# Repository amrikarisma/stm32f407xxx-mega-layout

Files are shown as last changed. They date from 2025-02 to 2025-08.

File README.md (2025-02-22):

# stm32f407xxx-mega-layout

## Made For Speeduino and RusEFI Firmware
This board is inspired by Pazi88 and Mega100 boards. Thank you very much to those who created the board first.

### Front
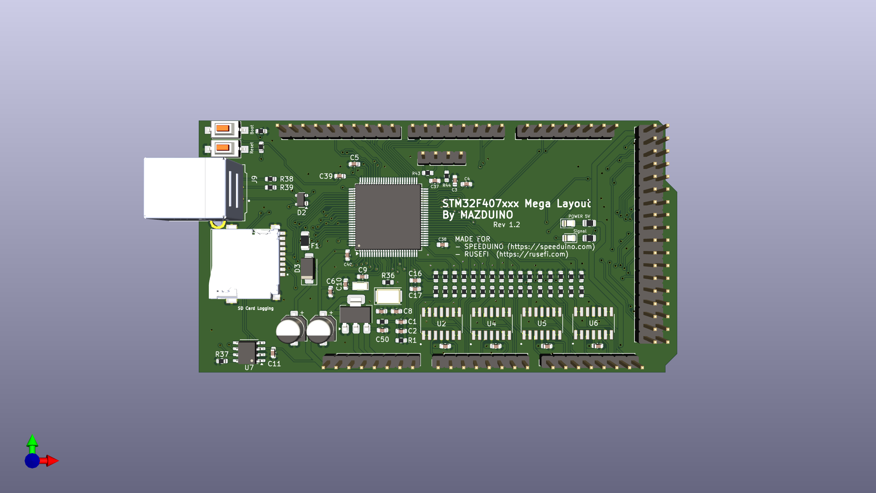
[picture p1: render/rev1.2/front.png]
front


### Back
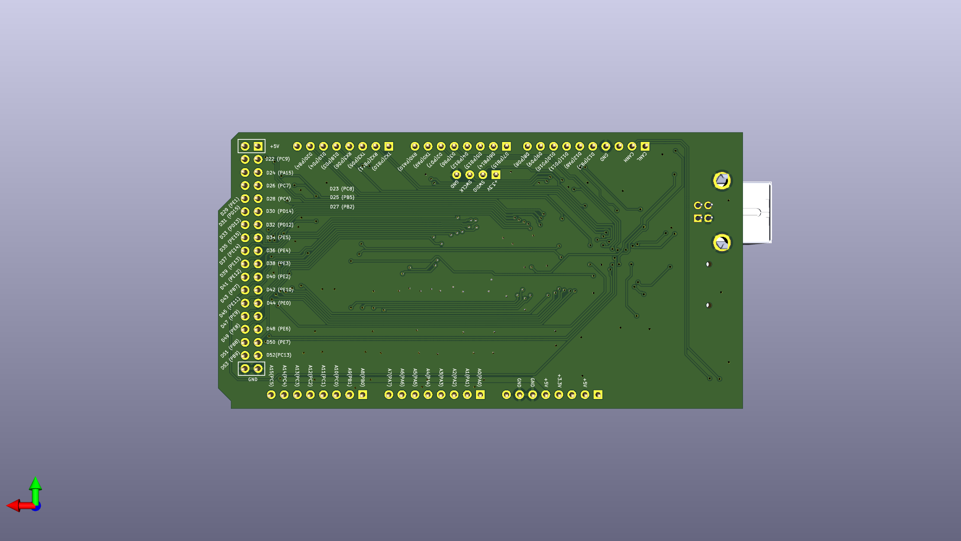
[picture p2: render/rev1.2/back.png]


### Schematic 
[schematic-stm32f407xxx-mega-layout.pdf](schematic-stm32f407xxx-mega-layout.pdf)

### Thanks to
- https://github.com/pazi88/STM32_mega
- https://github.com/rusefi/fw-custom-mega100/

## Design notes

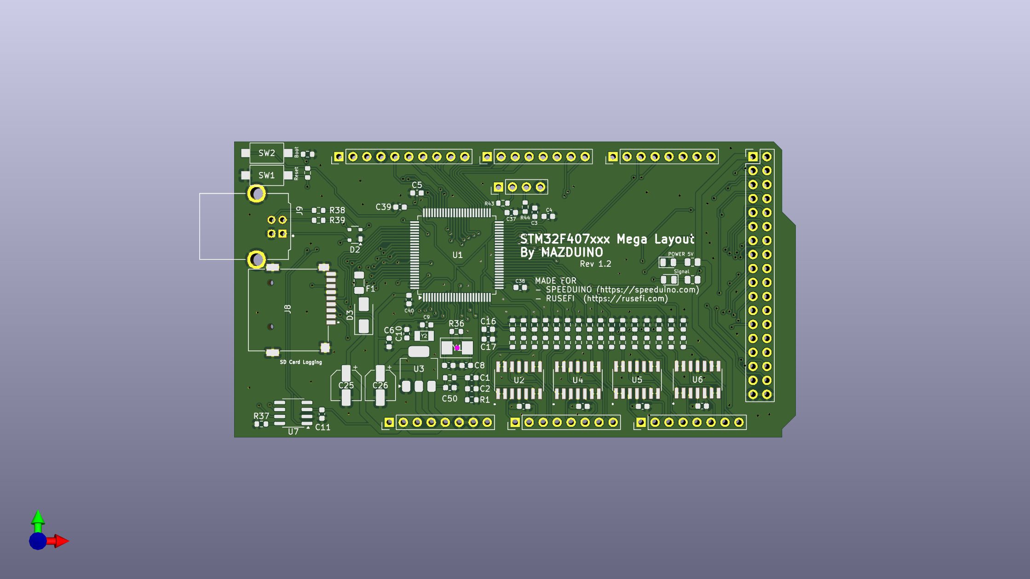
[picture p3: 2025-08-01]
render/rev1.2/STM32F407_Mega_converter.png

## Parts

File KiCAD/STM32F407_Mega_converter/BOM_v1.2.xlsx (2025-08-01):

Qty | Reference | Value | Footprint
2 | C1,C16 | 1uF | Capacitor_SMD:C_0603_1608Metric
12 | C2,C6,C11,C12,C13,C14,C15,C17,C37,C38,C39,C40 | 100nF | Capacitor_SMD:C_0603_1608Metric
2 | C3,C5 | 2.2uf | Capacitor_SMD:C_0603_1608Metric
1 | C4 | 1uf | Capacitor_SMD:C_0603_1608Metric
2 | C7,C8 | 12pF | Capacitor_SMD:C_0603_1608Metric
2 | C9,C10 | 20pF | Capacitor_SMD:C_0603_1608Metric
2 | C25,C26 | 47uf | Capacitor_SMD:CP_Elec_5x5.4
1 | C50 | 100nf | Capacitor_SMD:C_0603_1608Metric
1 | D2 | SP0503BAHT | Package_TO_SOT_SMD:SOT-143
1 | D3 | SS13 | Diode_SMD:D_SMA
1 | F1 | Polyfuse_Small | Fuse:Fuse_1206_3216Metric
5 | J1,J2,J3,J4,J5 | Conn_01x08_Pin | Connector_PinHeader_2.54mm:PinHeader_1x08_P2.54mm_Vertical
1 | J6 | Conn_01x10_Pin | Connector_PinHeader_2.54mm:PinHeader_1x10_P2.54mm_Vertical
1 | J7 | Conn_02x18 | Connector_PinHeader_2.54mm:PinHeader_2x18_P2.54mm_Vertical
1 | J8 | MSD-1-A | MSD_1_A:CUI_MSD-1-A
1 | J9 | AU-Y1007 | USB_TYPE-B:ASSMANN_USB_TYPE-B
1 | J10 | Conn_01x04_Pin | Connector_PinHeader_2.54mm:PinHeader_1x04_P2.54mm_Vertical
2 | LED1,LED2 | RED | LED_SMD:LED_0805_2012Metric
17 | R1,R7,R8,R9,R10,R15,R16,R17,R18,R23,R24,R25,R26,R31,R32,R33,R34 | 910 | Resistor_SMD:R_0603_1608Metric
17 | R2,R3,R4,R5,R6,R11,R12,R13,R14,R19,R20,R21,R22,R27,R28,R29,R30 | 470 | Resistor_SMD:R_0603_1608Metric
2 | R35,R42 | 470r | Resistor_SMD:R_0805_2012Metric
1 | R36 | 1M | Resistor_SMD:R_0603_1608Metric
1 | R37 | 4.7K | Resistor_SMD:R_0603_1608Metric
2 | R38,R39 | 22 | Resistor_SMD:R_0603_1608Metric
2 | R40,R41 | 10k | Resistor_SMD:R_0603_1608Metric
2 | R43,R44 | 10K | Resistor_SMD:R_0603_1608Metric
2 | SW1,SW2 | SW_Push | Button_Switch_SMD:SW_SPST_CK_RS282G05A3
1 | U1 | STM32F407VGTx | Package_QFP:LQFP-100_14x14mm_P0.5mm
4 | U2,U4,U5,U6 | MCP6004 | MCP6004T_I_SL:SOIC127P600X175-14N
1 | U3 | AMS1117-3.3 | Package_TO_SOT_SMD:SOT-223-3_TabPin2
1 | U7 | MCP2551-I-SN | Package_SO:SOIC-8_3.9x4.9mm_P1.27mm
1 | Y1 | 8Mhz | Crystal:Crystal_SMD_5032-2Pin_5.0x3.2mm
1 | Y2 | 32.768KHz | Crystal:Crystal_SMD_3215-2Pin_3.2x1.5mm

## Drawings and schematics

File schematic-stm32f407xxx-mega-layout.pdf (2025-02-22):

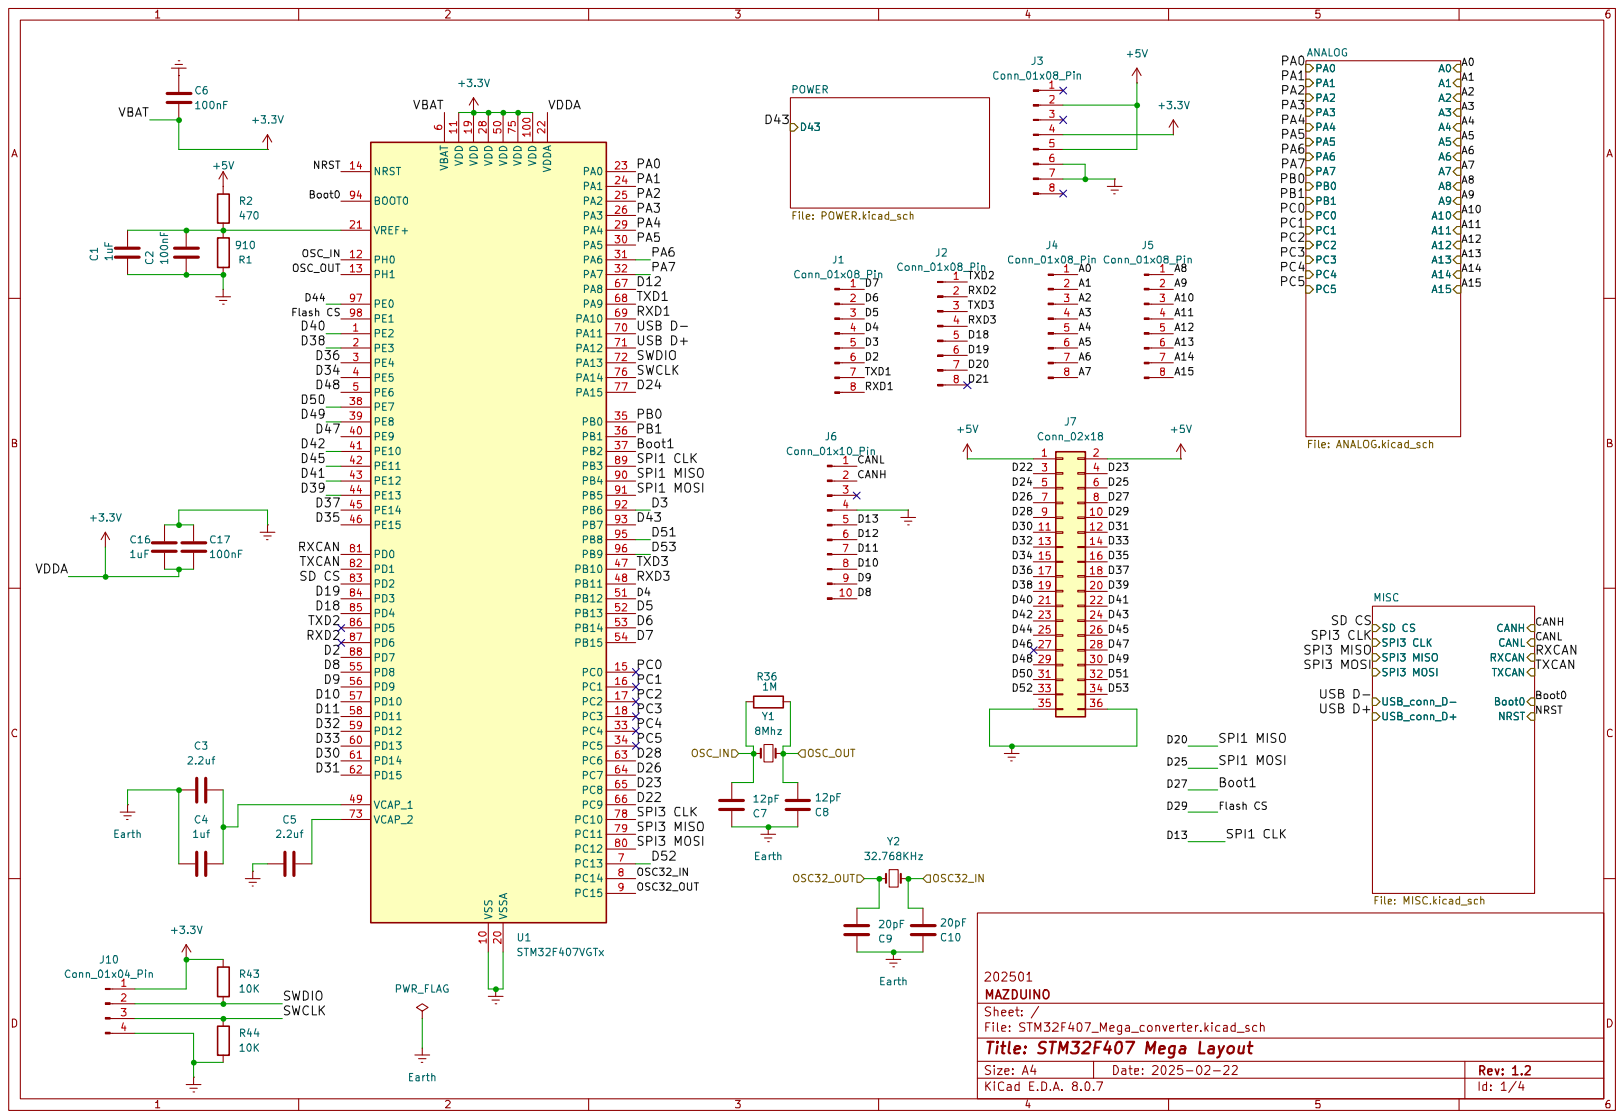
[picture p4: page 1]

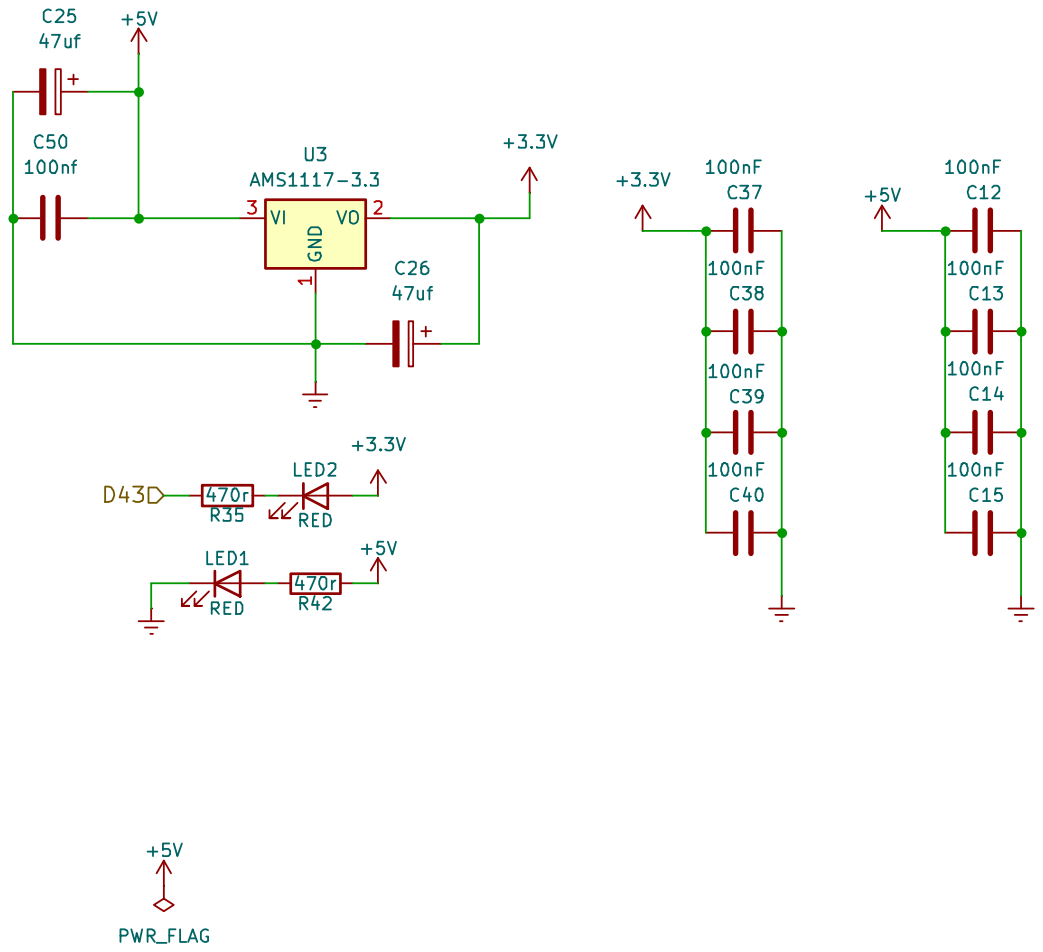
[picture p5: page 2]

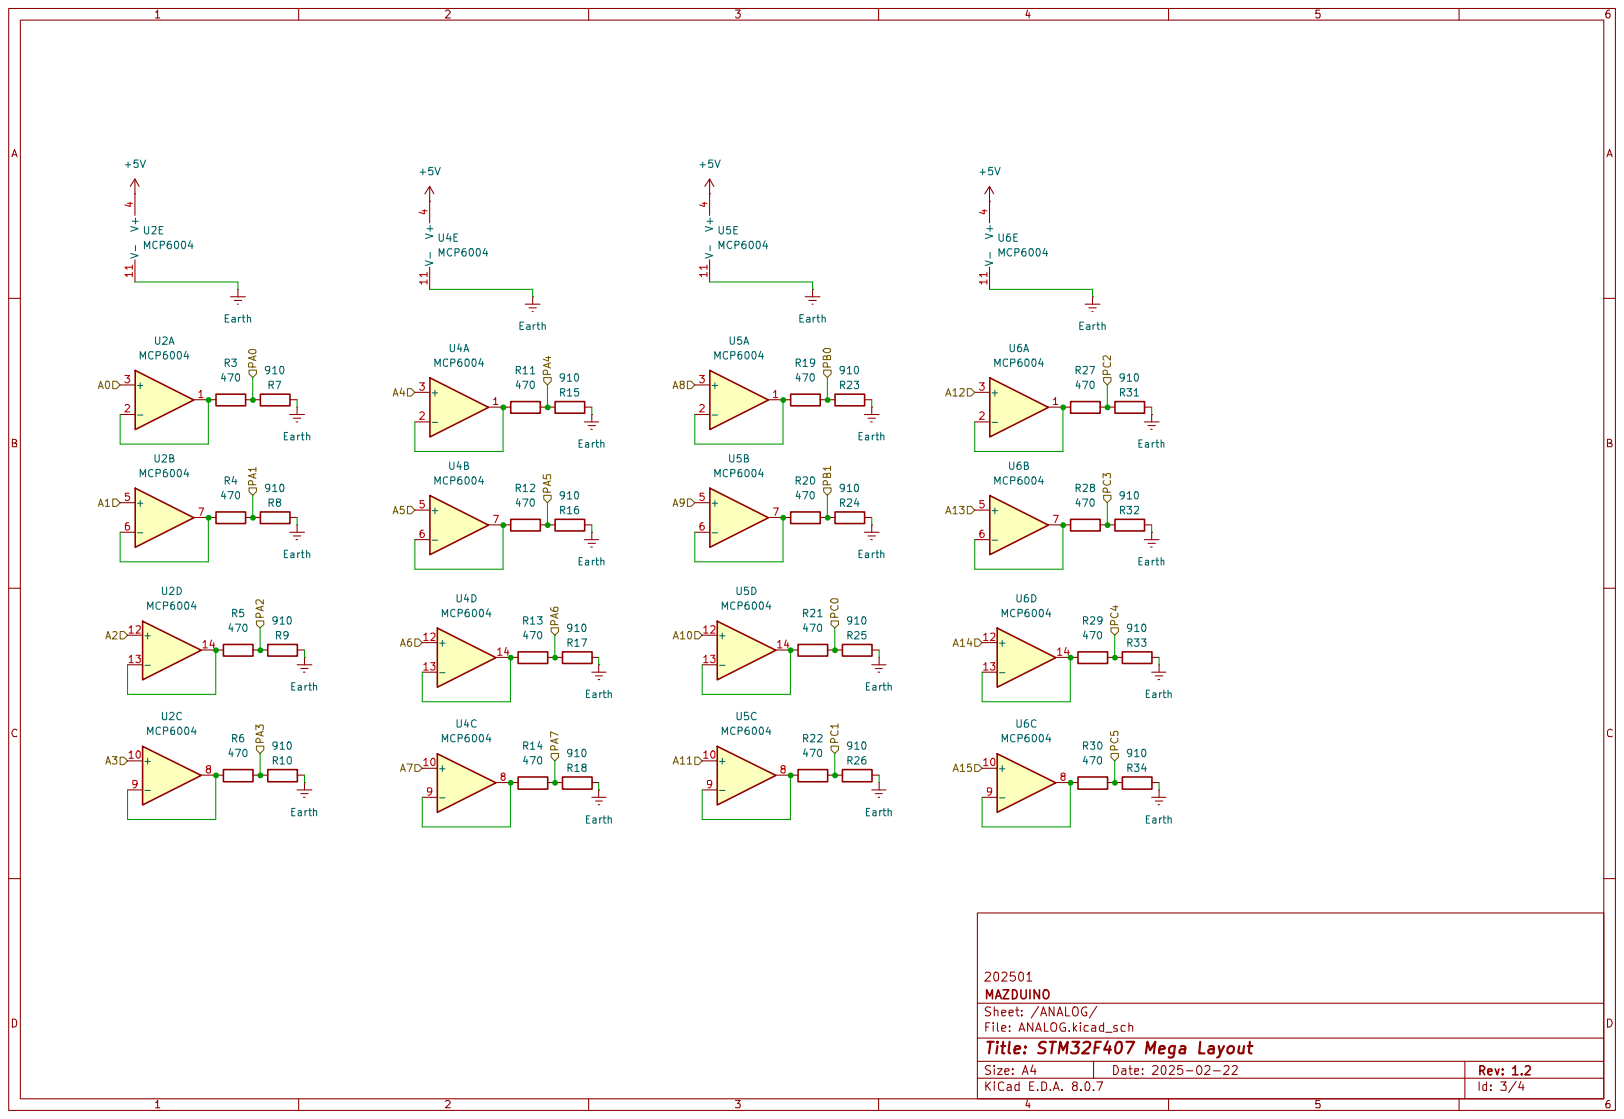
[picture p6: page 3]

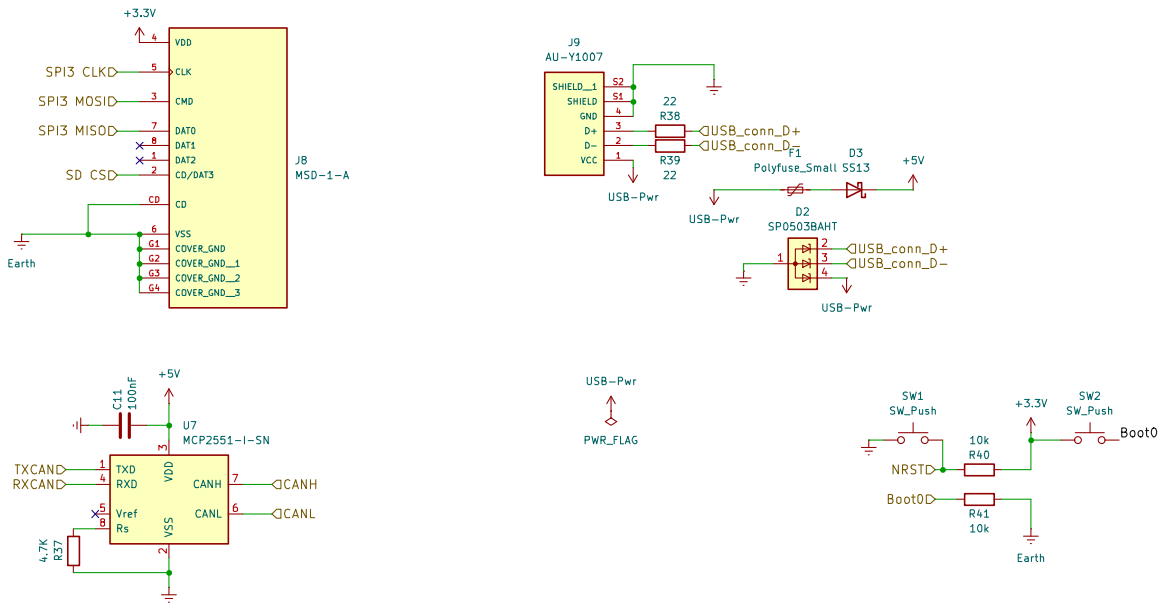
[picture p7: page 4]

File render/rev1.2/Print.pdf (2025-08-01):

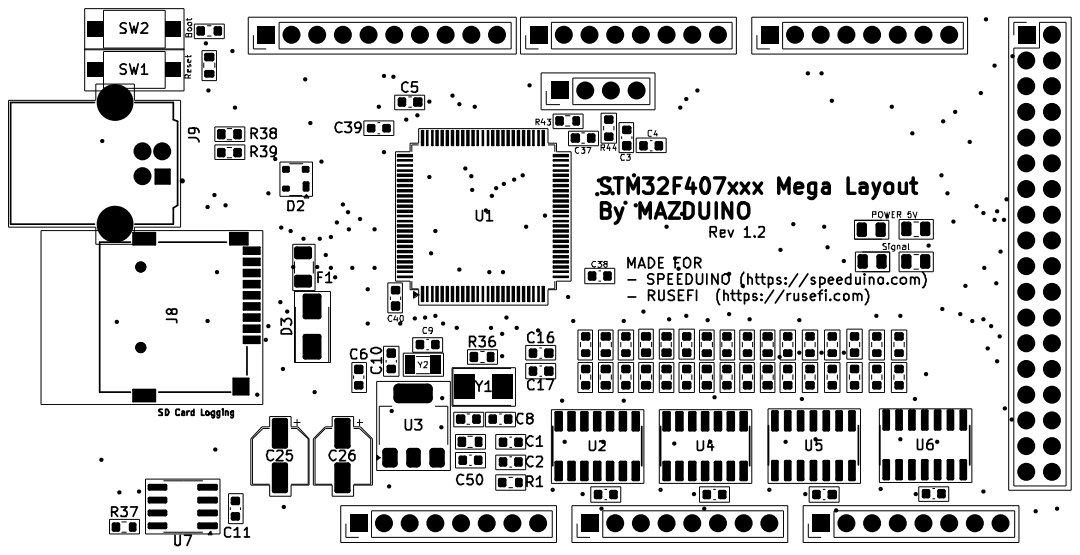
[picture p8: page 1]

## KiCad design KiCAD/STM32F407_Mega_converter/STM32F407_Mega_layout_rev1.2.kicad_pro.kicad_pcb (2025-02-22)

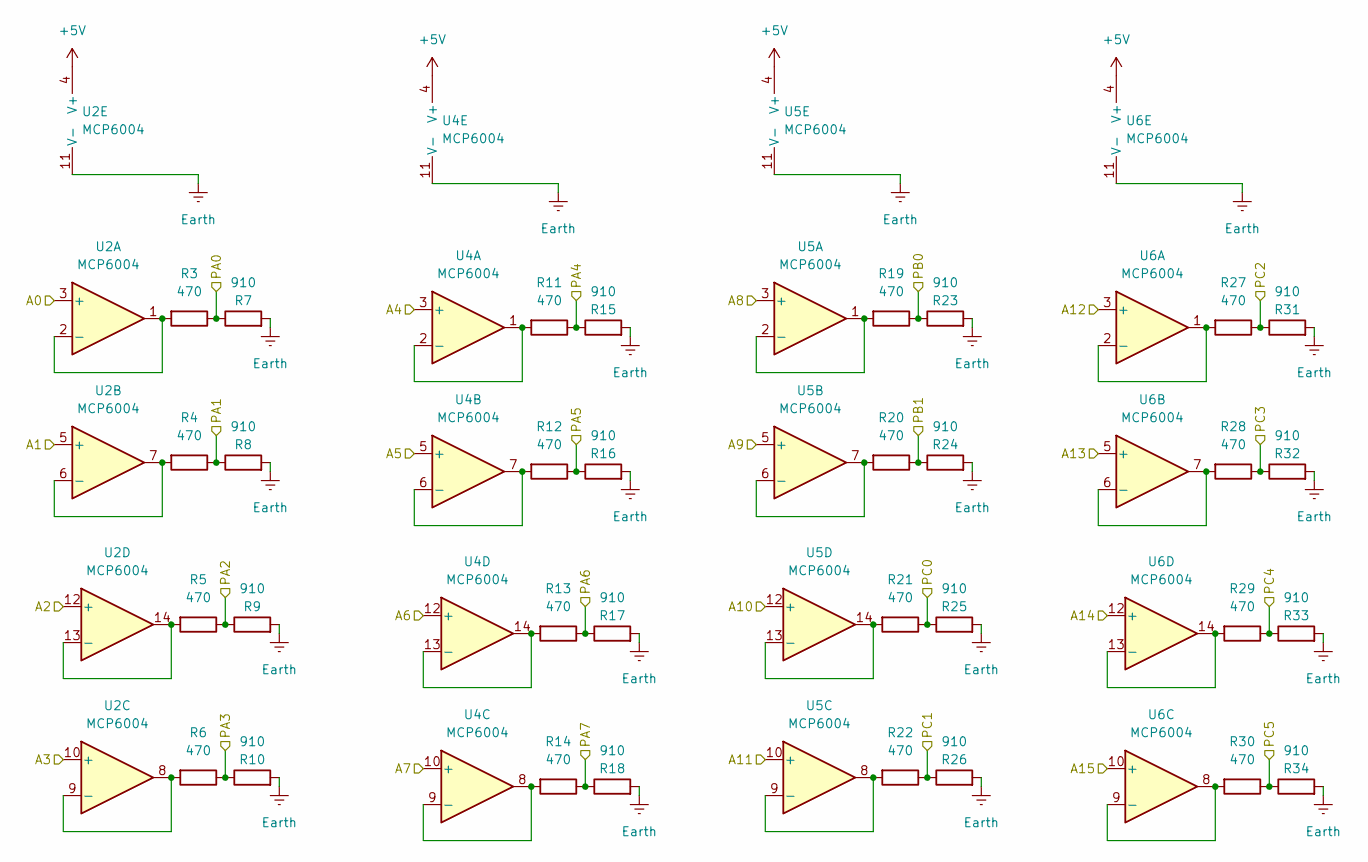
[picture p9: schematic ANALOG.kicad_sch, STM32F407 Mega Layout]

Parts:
R3, R4, R5, R6, R11, R12, R13, R14, R19, R20, R21, R22, R27, R28, R29, R30: 470; R_0603_1608Metric
R7, R8, R9, R10, R15, R16, R17, R18, R23, R24, R25, R26, R31, R32, R33, R34: 910; R_0603_1608Metric
U2, U4, U5, U6: MCP6004; SOIC127P600X175-14N

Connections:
+5V: U2.4 (V+), U4.4 (V+), U5.4 (V+), U6.4 (V+); also elsewhere on the board
/A0: U2.3 (+); also elsewhere on the board
/A1: U2.5 (+); also elsewhere on the board
/A2: U2.12 (+); also elsewhere on the board
/A3: U2.10 (+); also elsewhere on the board
/A4: U4.3 (+); also elsewhere on the board
/A5: U4.5 (+); also elsewhere on the board
/A6: U4.12 (+); also elsewhere on the board
/A7: U4.10 (+); also elsewhere on the board
/A8: U5.3 (+); also elsewhere on the board
/A9: U5.5 (+); also elsewhere on the board
/A10: U5.12 (+); also elsewhere on the board
/A11: U5.10 (+); also elsewhere on the board
/A12: U6.3 (+); also elsewhere on the board
/A13: U6.5 (+); also elsewhere on the board
/A14: U6.12 (+); also elsewhere on the board
/A15: U6.10 (+); also elsewhere on the board
/PA0: R3.1, R7.1; also elsewhere on the board
/PA1: R4.1, R8.1; also elsewhere on the board
/PA2: R5.1, R9.1; also elsewhere on the board
/PA3: R6.1, R10.1; also elsewhere on the board
/PA4: R11.1, R15.1; also elsewhere on the board
/PA5: R12.1, R16.1; also elsewhere on the board
/PA6: R13.1, R17.1; also elsewhere on the board
/PA7: R14.1, R18.1; also elsewhere on the board
/PB0: R19.1, R23.1; also elsewhere on the board
/PB1: R20.1, R24.1; also elsewhere on the board
/PC0: R21.1, R25.1; also elsewhere on the board
/PC1: R22.1, R26.1; also elsewhere on the board
/PC2: R27.1, R31.1; also elsewhere on the board
/PC3: R28.1, R32.1; also elsewhere on the board
/PC4: R29.1, R33.1; also elsewhere on the board
/PC5: R30.1, R34.1; also elsewhere on the board
Earth: R7.2, R8.2, R9.2, R10.2, R15.2, R16.2, R17.2, R18.2, R23.2, R24.2, R25.2, R26.2, R31.2, R32.2, R33.2, R34.2, U2.11 (V-), U4.11 (V-), U5.11 (V-), U6.11 (V-); also elsewhere on the board
unnamed: R3.2, U2.1, U2.2 (-)
unnamed: R4.2, U2.6 (-), U2.7
unnamed: R6.2, U2.8, U2.9 (-)
unnamed: R5.2, U2.13 (-), U2.14
unnamed: R11.2, U4.1, U4.2 (-)
unnamed: R12.2, U4.6 (-), U4.7
unnamed: R14.2, U4.8, U4.9 (-)
unnamed: R13.2, U4.13 (-), U4.14
unnamed: R19.2, U5.1, U5.2 (-)
unnamed: R20.2, U5.6 (-), U5.7
unnamed: R22.2, U5.8, U5.9 (-)
unnamed: R21.2, U5.13 (-), U5.14
unnamed: R27.2, U6.1, U6.2 (-)
unnamed: R28.2, U6.6 (-), U6.7
unnamed: R30.2, U6.8, U6.9 (-)
unnamed: R29.2, U6.13 (-), U6.14

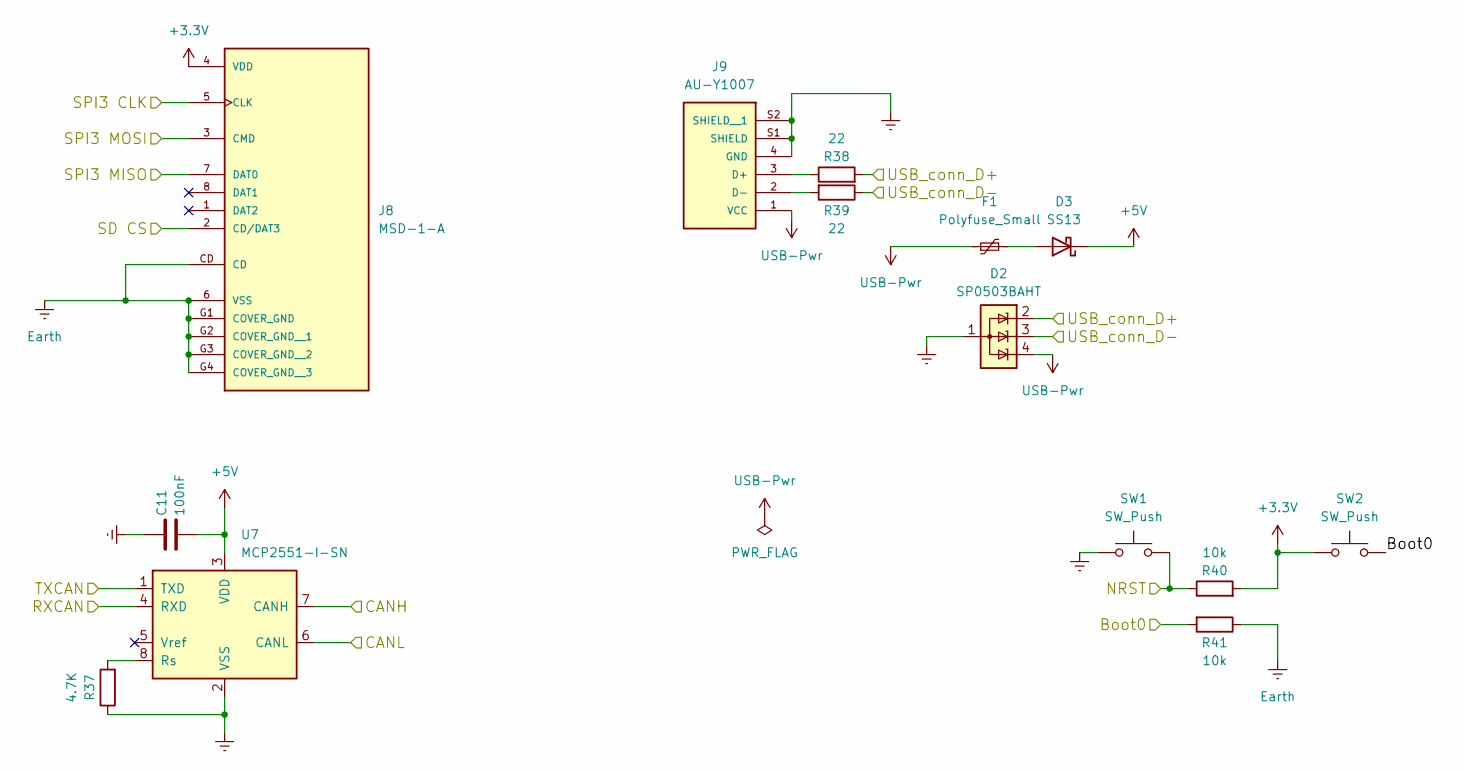
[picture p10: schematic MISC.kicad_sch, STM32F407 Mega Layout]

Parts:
C11: 100nF; C_0603_1608Metric
D2: SP0503BAHT; SOT-143
D3: SS13; D_SMA
F1: Polyfuse_Small; Fuse_1206_3216Metric
J8: MSD-1-A; CUI_MSD-1-A; PARTREV 1.0
J9: AU-Y1007; ASSMANN_USB_TYPE-B; PARTREV 01
R37: 4.7K; R_0603_1608Metric
R38, R39: 22; R_0603_1608Metric
R40, R41: 10k; R_0603_1608Metric
SW1, SW2: SW_Push; SW_SPST_CK_RS282G05A3
U7: MCP2551-I-SN; SOIC-8_3.9x4.9mm_P1.27mm

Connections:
+3.3V: J8.4 (VDD), R40.2, SW2.1; also elsewhere on the board
+5V: C11.2, D3.1 (K), U7.3 (VDD); also elsewhere on the board
/Boot0: R41.2, SW2.2; also elsewhere on the board
/CANH: U7.7 (CANH); also elsewhere on the board
/CANL: U7.6 (CANL); also elsewhere on the board
/NRST: R40.1, SW1.2; also elsewhere on the board
/RXCAN: U7.4 (RXD); also elsewhere on the board
/SD CS: J8.2 (CD/DAT3); also elsewhere on the board
/SPI3 CLK: J8.5 (CLK); also elsewhere on the board
/SPI3 MISO: J8.7 (DAT0); also elsewhere on the board
/SPI3 MOSI: J8.3 (CMD); also elsewhere on the board
/TXCAN: U7.1 (TXD); also elsewhere on the board
/USB D+: D2.2 (K), R38.2; also elsewhere on the board
/USB D-: D2.3 (K), R39.1; also elsewhere on the board
Earth: C11.1, D2.1 (A), J8.6 (VSS), J8.CD, J8.G1 (COVER_GND), J8.G2 (COVER_GND__1), J8.G3 (COVER_GND__2), J8.G4 (COVER_GND__3), J9.4 (GND), J9.S1 (SHIELD), J9.S2 (SHIELD__1), R37.1, R41.1, SW1.1, U7.2 (VSS); also elsewhere on the board
unnamed: D3.2 (A), F1.2
unnamed: J9.3 (D+), R38.1
unnamed: J9.2 (D-), R39.2
unnamed: R37.2, U7.8 (Rs)
USB-Pwr: D2.4 (K), F1.1, J9.1 (VCC)

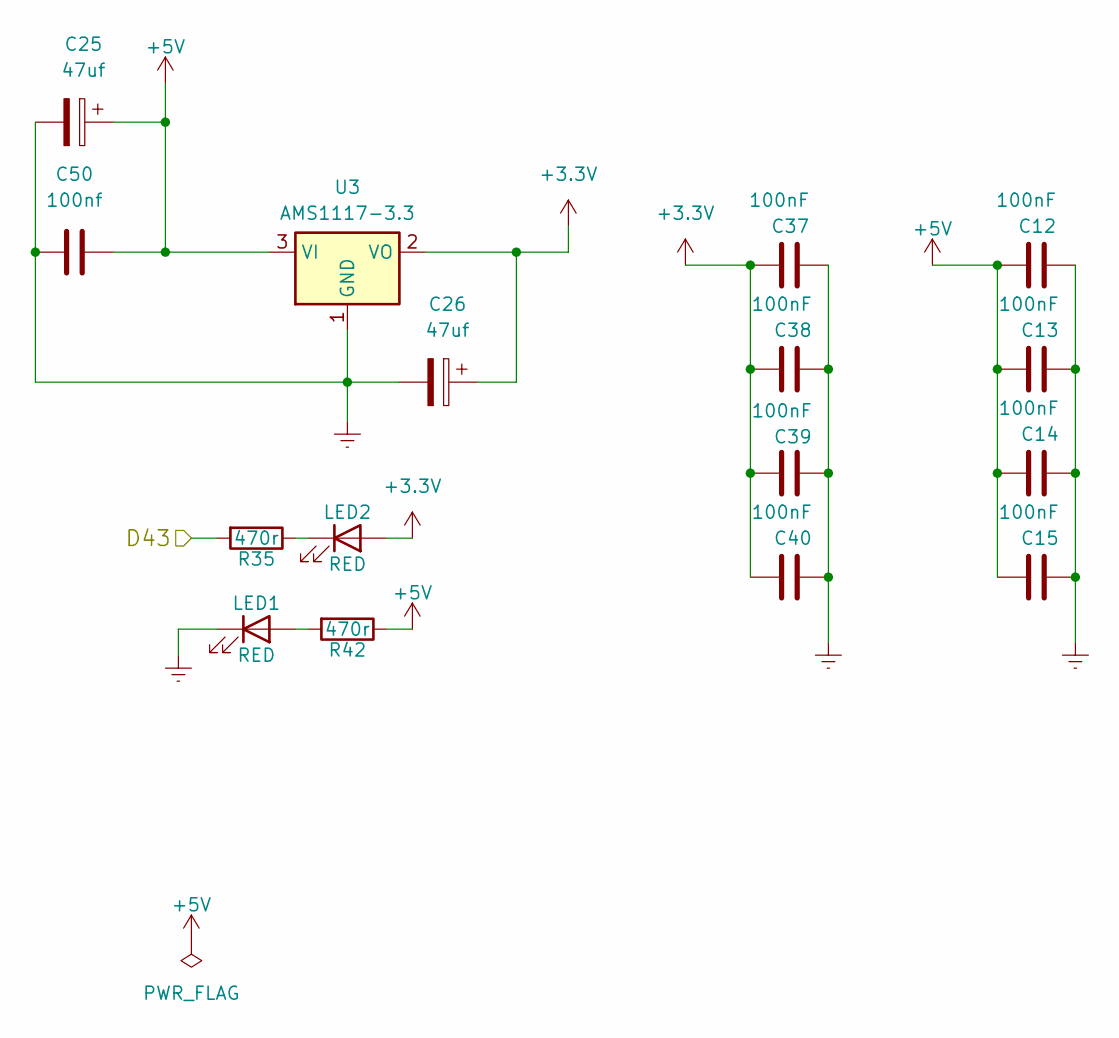
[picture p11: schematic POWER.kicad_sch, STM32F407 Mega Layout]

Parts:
C12, C13, C14, C15, C37, C38, C39, C40: 100nF; C_0603_1608Metric
C25, C26: 47uf; CP_Elec_5x5.4
C50: 100nf; C_0603_1608Metric
LED1, LED2: RED; LED_0805_2012Metric; MPN SML-310LTT86
R35, R42: 470r; R_0805_2012Metric; MPN RK73H2ATTD4700F
U3: AMS1117-3.3; SOT-223-3_TabPin2

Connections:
+3.3V: C26.1, C37.1, C38.1, C39.1, C40.1, LED2.2 (A), U3.2 (VO); also elsewhere on the board
+5V: C12.1, C13.1, C14.1, C15.1, C25.1, C50.2, R42.1, U3.3 (VI); also elsewhere on the board
/D43: R35.2; also elsewhere on the board
Earth: C12.2, C13.2, C14.2, C15.2, C25.2, C26.2, C37.2, C38.2, C39.2, C40.2, C50.1, LED1.1 (K), U3.1 (GND); also elsewhere on the board
unnamed: LED1.2 (A), R42.2
unnamed: LED2.1 (K), R35.1

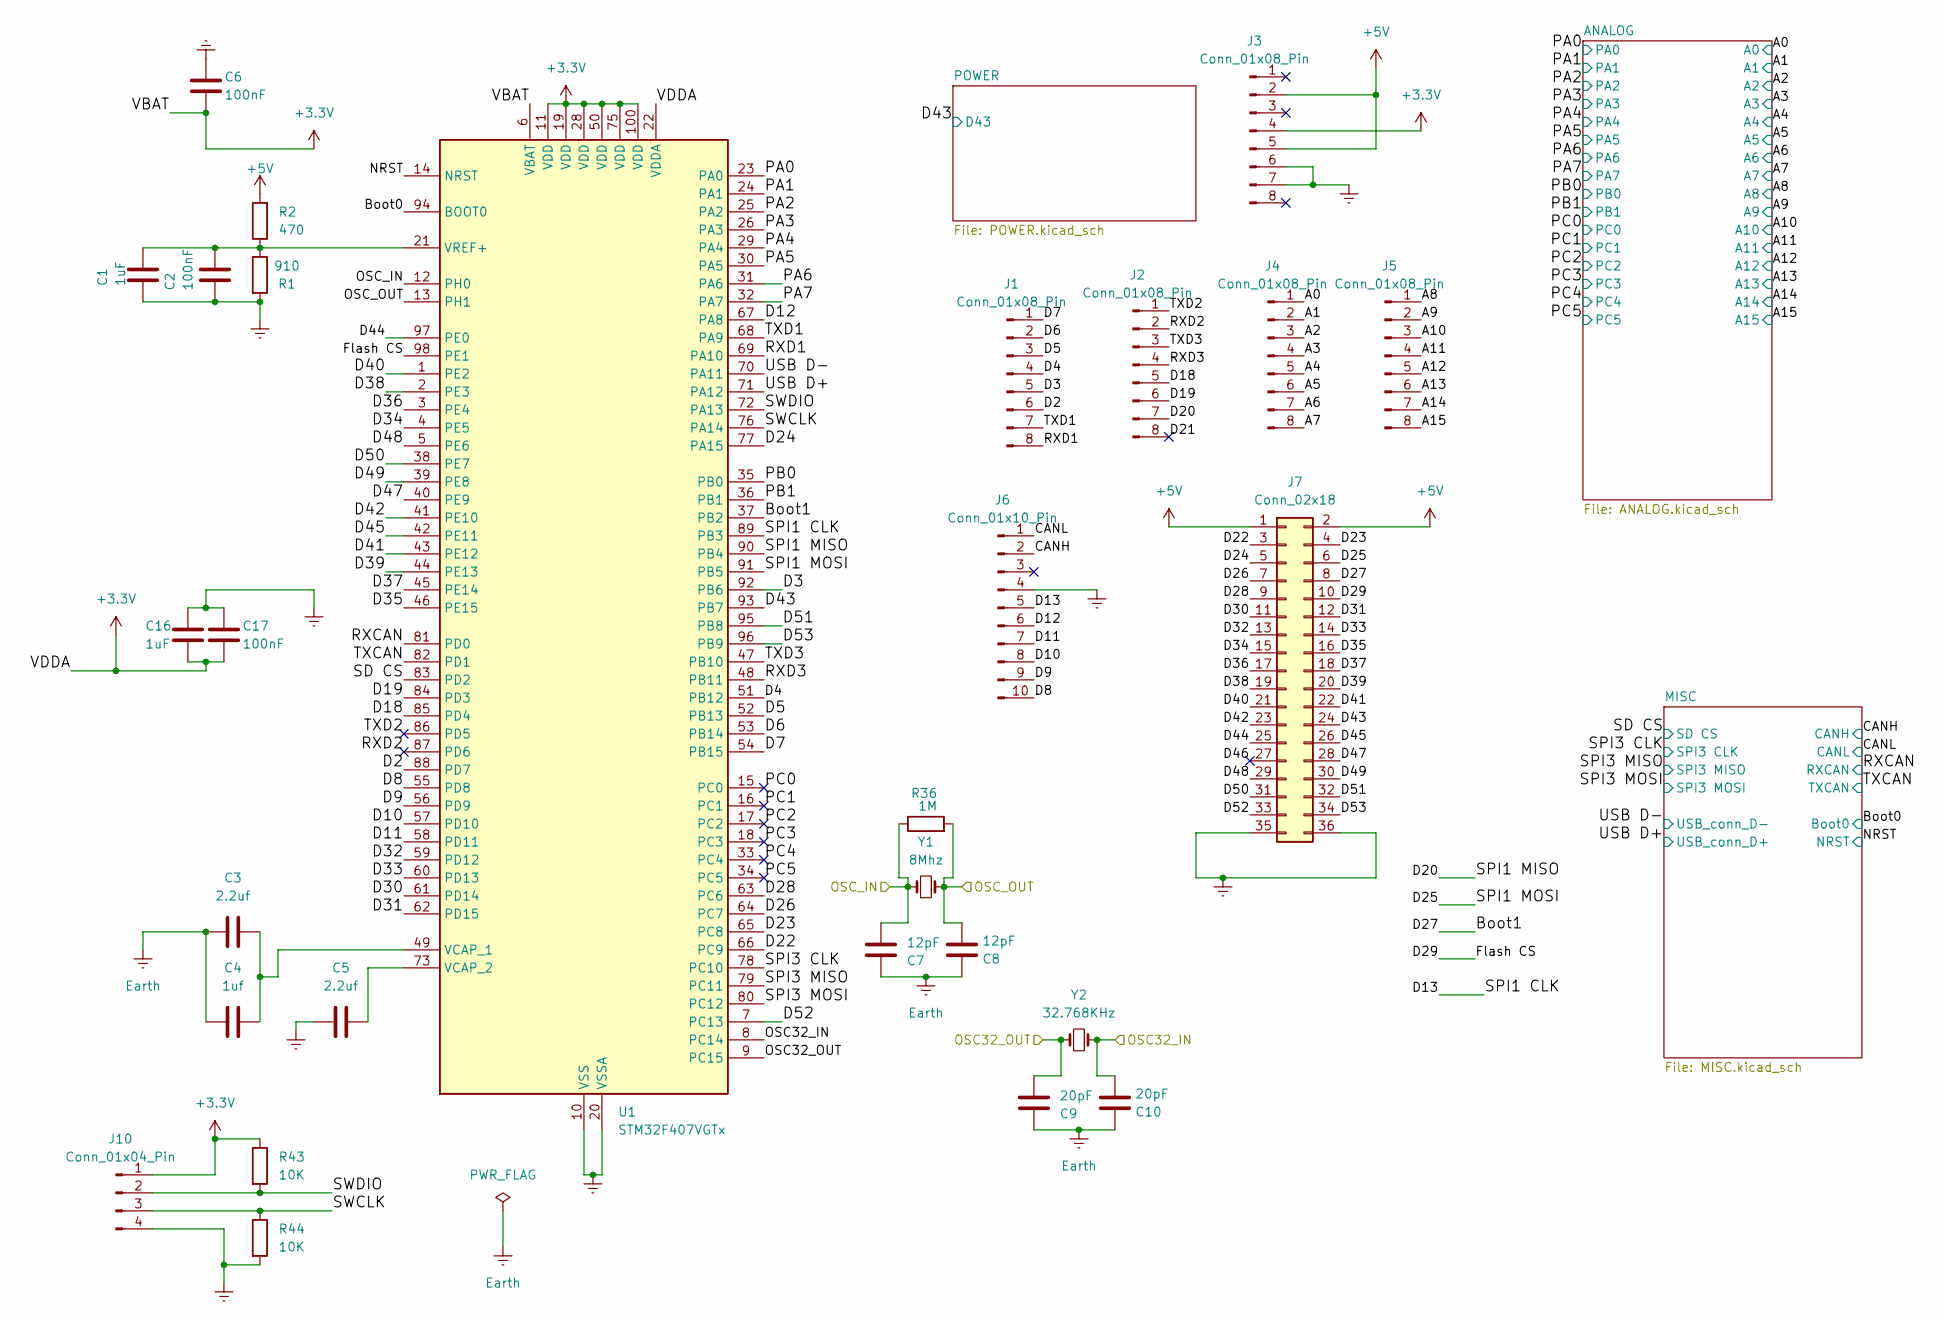
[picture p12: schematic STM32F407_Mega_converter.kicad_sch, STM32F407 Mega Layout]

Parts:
C1, C16: 1uF; C_0603_1608Metric
C2, C6, C17: 100nF; C_0603_1608Metric
C3, C5: 2.2uf; C_0603_1608Metric
C4: 1uf; C_0603_1608Metric
C7, C8: 12pF; C_0603_1608Metric
C9, C10: 20pF; C_0603_1608Metric
J1, J2, J3, J4, J5: Conn_01x08_Pin; PinHeader_1x08_P2.54mm_Vertical
J6: Conn_01x10_Pin; PinHeader_1x10_P2.54mm_Vertical
J7: Conn_02x18; PinHeader_2x18_P2.54mm_Vertical
J10: Conn_01x04_Pin; PinHeader_1x04_P2.54mm_Vertical
R1: 910; R_0603_1608Metric
R2: 470; R_0603_1608Metric
R36: 1M; R_0603_1608Metric
R43, R44: 10K; R_0603_1608Metric
U1: STM32F407VGTx; LQFP-100_14x14mm_P0.5mm
Y1: 8Mhz; Crystal_SMD_5032-2Pin_5.0x3.2mm
Y2: 32.768KHz; Crystal_SMD_3215-2Pin_3.2x1.5mm

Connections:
+3.3V: C6.2, C16.1, C17.2, J3.4, J10.1, R43.1, U1.6 (VBAT), U1.11 (VDD), U1.19 (VDD), U1.22 (VDDA), U1.28 (VDD), U1.50 (VDD), U1.75 (VDD), U1.100 (VDD); also elsewhere on the board
+5V: J3.2, J3.5, J7.1, J7.2, R2.2; also elsewhere on the board
/A0: J4.1; also elsewhere on the board
/A1: J4.2; also elsewhere on the board
/A2: J4.3; also elsewhere on the board
/A3: J4.4; also elsewhere on the board
/A4: J4.5; also elsewhere on the board
/A5: J4.6; also elsewhere on the board
/A6: J4.7; also elsewhere on the board
/A7: J4.8; also elsewhere on the board
/A8: J5.1; also elsewhere on the board
/A9: J5.2; also elsewhere on the board
/A10: J5.3; also elsewhere on the board
/A11: J5.4; also elsewhere on the board
/A12: J5.5; also elsewhere on the board
/A13: J5.6; also elsewhere on the board
/A14: J5.7; also elsewhere on the board
/A15: J5.8; also elsewhere on the board
/Boot0: U1.94 (BOOT0); also elsewhere on the board
/Boot1: J7.8, U1.37 (PB2)
/CANH: J6.2; also elsewhere on the board
/CANL: J6.1; also elsewhere on the board
/D2: J1.6, U1.88 (PD7)
/D3: J1.5, U1.92 (PB6)
/D4: J1.4, U1.51 (PB12)
/D5: J1.3, U1.52 (PB13)
/D6: J1.2, U1.53 (PB14)
/D7: J1.1, U1.54 (PB15)
/D8: J6.10, U1.55 (PD8)
/D9: J6.9, U1.56 (PD9)
/D10: J6.8, U1.57 (PD10)
/D11: J6.7, U1.58 (PD11)
/D12: J6.6, U1.67 (PA8)
/D13: J6.5, U1.89 (PB3)
/D18: J2.5, U1.85 (PD4)
/D19: J2.6, U1.84 (PD3)
/D20: J2.7, U1.90 (PB4)
/D21: J2.8
/D22: J7.3, U1.66 (PC9)
/D23: J7.4, U1.65 (PC8)
/D24: J7.5, U1.77 (PA15)
/D25: J7.6, U1.91 (PB5)
/D26: J7.7, U1.64 (PC7)
/D28: J7.9, U1.63 (PC6)
/D29: J7.10, U1.98 (PE1)
/D30: J7.11, U1.61 (PD14)
/D31: J7.12, U1.62 (PD15)
/D32: J7.13, U1.59 (PD12)
/D33: J7.14, U1.60 (PD13)
/D34: J7.15, U1.4 (PE5)
/D35: J7.16, U1.46 (PE15)
/D36: J7.17, U1.3 (PE4)
/D37: J7.18, U1.45 (PE14)
/D38: J7.19, U1.2 (PE3)
/D39: J7.20, U1.44 (PE13)
/D40: J7.21, U1.1 (PE2)
/D41: J7.22, U1.43 (PE12)
/D42: J7.23, U1.41 (PE10)
/D43: J7.24, U1.93 (PB7); also elsewhere on the board
/D44: J7.25, U1.97 (PE0)
/D45: J7.26, U1.42 (PE11)
/D46: J7.27
/D47: J7.28, U1.40 (PE9)
/D48: J7.29, U1.5 (PE6)
/D49: J7.30, U1.39 (PE8)
/D50: J7.31, U1.38 (PE7)
/D51: J7.32, U1.95 (PB8)
/D52: J7.33, U1.7 (PC13)
/D53: J7.34, U1.96 (PB9)
/NRST: U1.14 (NRST); also elsewhere on the board
/OSC32_IN: C10.1, U1.8 (PC14), Y2.2
/OSC32_OUT: C9.1, U1.9 (PC15), Y2.1
/OSC_IN: C7.1, R36.1, U1.12 (PH0), Y1.1
/OSC_OUT: C8.1, R36.2, U1.13 (PH1), Y1.2
/PA0: U1.23 (PA0); also elsewhere on the board
/PA1: U1.24 (PA1); also elsewhere on the board
/PA2: U1.25 (PA2); also elsewhere on the board
/PA3: U1.26 (PA3); also elsewhere on the board
/PA4: U1.29 (PA4); also elsewhere on the board
/PA5: U1.30 (PA5); also elsewhere on the board
/PA6: U1.31 (PA6); also elsewhere on the board
/PA7: U1.32 (PA7); also elsewhere on the board
/PB0: U1.35 (PB0); also elsewhere on the board
/PB1: U1.36 (PB1); also elsewhere on the board
/PC0: U1.15 (PC0); also elsewhere on the board
/PC1: U1.16 (PC1); also elsewhere on the board
/PC2: U1.17 (PC2); also elsewhere on the board
/PC3: U1.18 (PC3); also elsewhere on the board
/PC4: U1.33 (PC4); also elsewhere on the board
/PC5: U1.34 (PC5); also elsewhere on the board
/RXCAN: U1.81 (PD0); also elsewhere on the board
/RXD1: J1.8, U1.69 (PA10)
/RXD2: J2.2, U1.87 (PD6)
/RXD3: J2.4, U1.48 (PB11)
/SD CS: U1.83 (PD2); also elsewhere on the board
/SPI3 CLK: U1.78 (PC10); also elsewhere on the board
/SPI3 MISO: U1.79 (PC11); also elsewhere on the board
/SPI3 MOSI: U1.80 (PC12); also elsewhere on the board
/SWCLK: J10.3, R44.1, U1.76 (PA14)
/SWDIO: J10.2, R43.2, U1.72 (PA13)
/TXCAN: U1.82 (PD1); also elsewhere on the board
/TXD1: J1.7, U1.68 (PA9)
/TXD2: J2.1, U1.86 (PD5)
/TXD3: J2.3, U1.47 (PB10)
/USB D+: U1.71 (PA12); also elsewhere on the board
/USB D-: U1.70 (PA11); also elsewhere on the board
Earth: C1.1, C2.2, C3.1, C4.1, C5.1, C6.1, C7.2, C8.2, C9.2, C10.2, C16.2, C17.1, J3.6, J3.7, J6.4, J7.35, J7.36, J10.4, R1.2, R44.2, U1.10 (VSS), U1.20 (VSSA), U1.27 (VSS), U1.74 (VSS), U1.99 (VSS); also elsewhere on the board
unnamed: C3.2, C4.2, U1.49 (VCAP_1)
unnamed: C5.2, U1.73 (VCAP_2)
unnamed: C1.2, C2.1, R1.1, R2.1, U1.21 (VREF+)

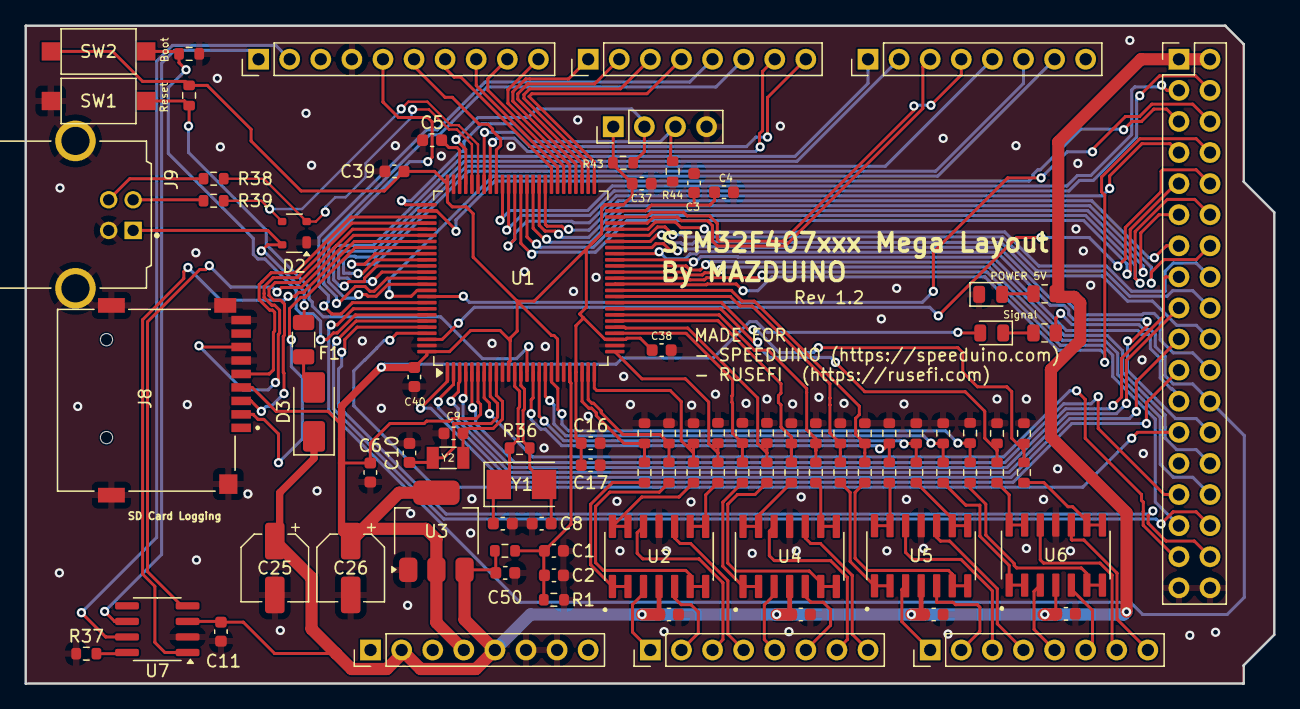
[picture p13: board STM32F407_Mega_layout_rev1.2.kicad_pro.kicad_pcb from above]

Board: 2 copper layers, 102.0 x 53.8 mm, 94 parts (0 on the bottom side), 131 nets.

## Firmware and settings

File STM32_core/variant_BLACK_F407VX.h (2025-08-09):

/*
 *******************************************************************************
 * Copyright (c) 2017-2021, STMicroelectronics
 * All rights reserved.
 *
 * This software component is licensed by ST under BSD 3-Clause license,
 * the "License"; You may not use this file except in compliance with the
 * License. You may obtain a copy of the License at:
 *                        opensource.org/licenses/BSD-3-Clause
 *
 *******************************************************************************
 */
#pragma once

/*----------------------------------------------------------------------------
 *        STM32 pins number
 *----------------------------------------------------------------------------*/
#define PC9                      0 // D22
#define PC8                      1 // D23
#define PD7                      2 // D2
#define PB6                      3 // D3
#define PB12                     4 // D4
#define PB13                     5 // D5
#define PB14                      6 // D6
#define PB15                      7 // D7
#define PD8                     8 // D8
#define PD9                     9 // D9
#define PD10                     10 // D10
#define PD11                     11 // D11
#define PA8                      12 // D12
#define PB3                      13 // D13
#define PB10                      14 // D16
#define PB11                      15 // D17
#define PC12                     16 // SPI3 MOSI for SD
#define PC11                     17 // SPI3 MISO for SD
#define PD4                      18 // D18
#define PD3                      19 // D19
#define PD0                      20 // CAN RX
#define PD1                      21 // CAN TX
#define PA10                     22 // D0
#define PA9                      23 // D1
#define PA15                     24 // D24
#define PD5                     25 // D14
#define PC7                      26 // D26
#define PD6                     27 // D15
#define PC6                      28 // D28
#define PC10                     29 // SPI3 CLK for SD
#define PD14                     30 // D30
#define PD15                     31 // D31
#define PD12                     32 // D32
#define PD13                     33 // D33
#define PE5                      34 // D34
#define PE15                     35 // D35
#define PE4                      36 // D36
#define PE14                     37 // D37
#define PE3                      38 // D38
#define PE13                     39 // D39
#define PE2                      40 // D40
#define PE12                     41 // D41
#define PE10                     42 // D42
#define PB7                      43 // D43
#define PE0                      44 // SPI1 CLK
#define PE11                     45 // D45
#define PD2                      46 // D46 // SD CS
#define PE9                      47 // D47
#define PE6                      48 // D48
#define PE8                      49 // D49
#define PE7                      50 // D50
#define PB8                      51 // D51
#define PC13                     52 // D52
#define PB9                      53 // D53
#define PA0                      PIN_A0
#define PA1                      PIN_A1
#define PA2                      PIN_A2
#define PA3                      PIN_A3
#define PA4                      PIN_A4
#define PA5                      PIN_A5
#define PA6                      PIN_A6
#define PA7                      PIN_A7
#define PB0                      PIN_A8
#define PB1                      PIN_A9
#define PC0                      PIN_A10
#define PC1                      PIN_A11
#define PC2                      PIN_A12
#define PC3                      PIN_A13
#define PC4                      PIN_A14
#define PC5                      PIN_A15
#define PA11                     70 // USB_DP
#define PA12                     71 // USB_DM
#define PE1                      72 // SPI-Flash CS
#define PB4                      73 // SPI1 MOSI
#define PB5                      74 // SPI1 MISO

// Alternate pins number
#define PA0_ALT1                (PA0  | ALT1)
#define PA0_ALT2                (PA0  | ALT2)
#define PA1_ALT1                (PA1  | ALT1)
#define PA1_ALT2                (PA1  | ALT2)
#define PA2_ALT1                (PA2  | ALT1)
#define PA2_ALT2                (PA2  | ALT2)
#define PA3_ALT1                (PA3  | ALT1)
#define PA3_ALT2                (PA3  | ALT2)
#define PA4_ALT1                (PA4  | ALT1)
#define PA5_ALT1                (PA5  | ALT1)
#define PA6_ALT1                (PA6  | ALT1)
#define PA7_ALT1                (PA7  | ALT1)
#define PA7_ALT2                (PA7  | ALT2)
#define PA7_ALT3                (PA7  | ALT3)
#define PA15_ALT1               (PA15 | ALT1)
#define PB0_ALT1                (PB0  | ALT1)
#define PB0_ALT2                (PB0  | ALT2)
#define PB1_ALT1                (PB1  | ALT1)
#define PB1_ALT2                (PB1  | ALT2)
#define PB3_ALT1                (PB3  | ALT1)
#define PB4_ALT1                (PB4  | ALT1)
#define PB5_ALT1                (PB5  | ALT1)
#define PB8_ALT1                (PB8  | ALT1)
#define PB9_ALT1                (PB9  | ALT1)
#define PB14_ALT1               (PB14 | ALT1)
#define PB14_ALT2               (PB14 | ALT2)
#define PB15_ALT1               (PB15 | ALT1)
#define PB15_ALT2               (PB15 | ALT2)
#define PC0_ALT1                (PC0  | ALT1)
#define PC0_ALT2                (PC0  | ALT2)
#define PC1_ALT1                (PC1  | ALT1)
#define PC1_ALT2                (PC1  | ALT2)
#define PC2_ALT1                (PC2  | ALT1)
#define PC2_ALT2                (PC2  | ALT2)
#define PC3_ALT1                (PC3  | ALT1)
#define PC3_ALT2                (PC3  | ALT2)
#define PC4_ALT1                (PC4  | ALT1)
#define PC5_ALT1                (PC5  | ALT1)
#define PC6_ALT1                (PC6  | ALT1)
#define PC7_ALT1                (PC7  | ALT1)
#define PC8_ALT1                (PC8  | ALT1)
#define PC9_ALT1                (PC9  | ALT1)
#define PC10_ALT1               (PC10 | ALT1)
#define PC11_ALT1               (PC11 | ALT1)

#define NUM_DIGITAL_PINS        75
#define NUM_ANALOG_INPUTS       16

// On-board LED pin number

#ifndef LED_BUILTIN
  #define LED_BUILTIN           PB7
#endif

// Below SPI and I2C definitions already done in the core
// Could be redefined here if differs from the default one
// SPI Definitions
#ifndef PIN_SPI_SS
  #define PIN_SPI_SS            PE1 // W25Q16 (on board flash)
#endif
#ifndef PIN_SPI_SS1
  #define PIN_SPI_SS1           PE1 // W25Q16 (on board flash)
#endif
#ifndef PIN_SPI_MOSI
  #define PIN_SPI_MOSI          PB5 // W25Q16 (on board flash)
#endif
#ifndef PIN_SPI_MISO
  #define PIN_SPI_MISO          PB4 // W25Q16 (on board flash)
#endif
#ifndef PIN_SPI_SCK
  #define PIN_SPI_SCK           PB3 // W25Q16 (on board flash)
#endif

// I2C Definitions
#ifndef PIN_WIRE_SDA
  #define PIN_WIRE_SDA          PB9
#endif
#ifndef PIN_WIRE_SCL
  #define PIN_WIRE_SCL          PB8
#endif
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

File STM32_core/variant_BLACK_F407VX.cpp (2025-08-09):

/*
 *******************************************************************************
 * Copyright (c) 2017-2021, STMicroelectronics
 * All rights reserved.
 *
 * This software component is licensed by ST under BSD 3-Clause license,
 * the "License"; You may not use this file except in compliance with the
 * License. You may obtain a copy of the License at:
 *                        opensource.org/licenses/BSD-3-Clause
 *
 *******************************************************************************
 */
#if defined(ARDUINO_BLACK_F407VE) || defined(ARDUINO_BLACK_F407VG)

#include "pins_arduino.h"

// Digital PinName array
// This array allows to wrap Arduino pin number(Dx or x)
// to STM32 PinName (PX_n)
const PinName digitalPin[] = {
  PC_9,   PC_8,   // D0, D1
  PD_7,   PB_6,   // D2, D3
  PB_12,  PB_13,  // D4, D5
  PB_14,  PB_15,  // D6, D7
  PD_8,   PD_9,   // D8, D9
  PD_10,  PD_11,  // D10, D11
  PA_8,   PB_3,   // D12, D13
  PB_10,  PB_11,  // D14, D15
  PC_12,  PC_11,  // D16, D17
  PD_4,   PD_3,   // D18, D19
  PD_0,   PD_1,   // D20, D21
  PA_10,  PA_9,   // D22, D23
  PA_15,  PD_5,   // D24, D25
  PC_7,   PD_6,   // D26, D27
  PC_6,   PC_10,  // D28, D29
  PD_14,  PD_15,  // D30, D31
  PD_12,  PD_13,  // D32, D33
  PE_5,   PE_15,  // D34, D35
  PE_4,   PE_14,  // D36, D37
  PE_3,   PE_13,  // D38, D39
  PE_2,   PE_12,  // D40, D41
  PE_10,  PB_7,   // D42, D43
  PB_3,   PE_11,  // D44, D45
  PE_0,   PE_9,   // D46, D47
  PE_6,   PE_8,   // D48, D49
  PE_7,   PB_8,   // D50, D51
  PC_13,  PB_9,   // D52, D53
  PA_0,   PA_1,   // A0, A1
  PA_2,   PA_3,   // A2, A3
  PA_4,   PA_5,   // A4, A5
  PA_6,   PA_7,   // A6, A7
  PB_0,   PB_1,   // A8, A9
  PC_0,   PC_1,   // A10, A11
  PC_2,   PC_3,   // A12, A13
  PC_4,   PC_5,   // A14, A15
  PA_11,  PA_12,  // D70, D71
  PE_1,   PB_4,   // D72, D73
  PB_5,           // D74
};

// Analog (Ax) pin number array
const uint32_t analogInputPin[] = {
  54, // A0
  55, // A1
  56, // A2
  57, // A3
  58, // A4
  59, // A5
  60, // A6
  61, // A7
  62, // A8
  63, // A9
  64, // A10
  65, // A11
  66, // A12
  67, // A13
  68, // A14
  69  // A15

};

// ----------------------------------------------------------------------------

#ifdef __cplusplus
extern "C" {
#endif

/**
  * @brief  System Clock Configuration
  * @param  None
  * @retval None
  */
WEAK void SystemClock_Config(void)
{

  RCC_OscInitTypeDef RCC_OscInitStruct = {};
  RCC_ClkInitTypeDef RCC_ClkInitStruct = {};

  /**Configure the main internal regulator output voltage
  */
  __HAL_RCC_PWR_CLK_ENABLE();

  __HAL_PWR_VOLTAGESCALING_CONFIG(PWR_REGULATOR_VOLTAGE_SCALE1);

  /**Initializes the CPU, AHB and APB busses clocks
  */
  RCC_OscInitStruct.OscillatorType = RCC_OSCILLATORTYPE_HSE;
  RCC_OscInitStruct.HSEState = RCC_HSE_ON;
  RCC_OscInitStruct.PLL.PLLState = RCC_PLL_ON;
  RCC_OscInitStruct.PLL.PLLSource = RCC_PLLSOURCE_HSE;
  RCC_OscInitStruct.PLL.PLLM = 8;
  RCC_OscInitStruct.PLL.PLLN = 336;
  RCC_OscInitStruct.PLL.PLLP = RCC_PLLP_DIV2;
  RCC_OscInitStruct.PLL.PLLQ = 7;
  if (HAL_RCC_OscConfig(&RCC_OscInitStruct) != HAL_OK) {
    Error_Handler();
  }

  /**Initializes the CPU, AHB and APB busses clocks
  */
  RCC_ClkInitStruct.ClockType = RCC_CLOCKTYPE_HCLK | RCC_CLOCKTYPE_SYSCLK
                                | RCC_CLOCKTYPE_PCLK1 | RCC_CLOCKTYPE_PCLK2;
  RCC_ClkInitStruct.SYSCLKSource = RCC_SYSCLKSOURCE_PLLCLK;
  RCC_ClkInitStruct.AHBCLKDivider = RCC_SYSCLK_DIV1;
  RCC_ClkInitStruct.APB1CLKDivider = RCC_HCLK_DIV4;
  RCC_ClkInitStruct.APB2CLKDivider = RCC_HCLK_DIV2;

  if (HAL_RCC_ClockConfig(&RCC_ClkInitStruct, FLASH_LATENCY_5) != HAL_OK) {
    Error_Handler();
  }

  /* Ensure CCM RAM clock is enabled */
  __HAL_RCC_CCMDATARAMEN_CLK_ENABLE();

}

#ifdef __cplusplus
}
#endif

#endif /* ARDUINO_BLACK_F407VE || ARDUINO_BLACK_F407VG */

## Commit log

2025-02-20 add kicad
    [ANALOG.kicad_sch, MISC.kicad_sch, POWER.kicad_sch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]
2025-02-22 update rev1.2 fix sdcard conflict with ua4c board connector
    [ANALOG.kicad_sch, MISC.kicad_sch, POWER.kicad_sch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]
2025-08-01 add firmware speeduino
    [BOM_v1.2.xlsx, STM32F407_Mega_converter.csv]
2025-08-09 update mapping arduino digital ppin
2025-08-09 fix mapping pin
